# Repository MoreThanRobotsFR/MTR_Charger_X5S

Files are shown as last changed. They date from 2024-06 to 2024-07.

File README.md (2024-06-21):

<!-- markdownlint-configure-file { "MD004": { "style": "consistent" } } -->
<!-- markdownlint-disable MD033 -->
<p align="center">
    <a href="https://morethanrobotsfr.github.io/MoreThanRobots/">
        MTR
    </a>
    <br>
    <strong>Coding, Hardware and fun !</strong>
</p>
<!-- markdownlint-enable MD033 -->

<body style="background-color:#FFBF00;">
</body>

# MoreThanRobots
* Check the [YOUTUBE-EN-FR](https://www.youtube.com/@morethanrobots) channel.

# Coding
* C/C++
* Python
* MicroPython
* CircuitPython 

# Hardward
* Arduino Uno / Mega / Nano
* Raspberry Pi / Pico / RP2040
* NodeMCU ESP8266 / ESP32

# Schematic
* Kicad
* Altium designer

# Last Project
* [MTR Reflow Plate](https://github.com/MoreThanRobotsFR/MTR_Reflow_Plate)
* [MTR Tiny MD](https://github.com/MoreThanRobotsFR/MTR_Tiny_MD)
* [MTR Multisensor](https://github.com/MoreThanRobotsFR/MTR_C3_TempHum)

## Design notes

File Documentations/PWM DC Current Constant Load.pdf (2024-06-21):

# RC Filter Design for PWM Signal

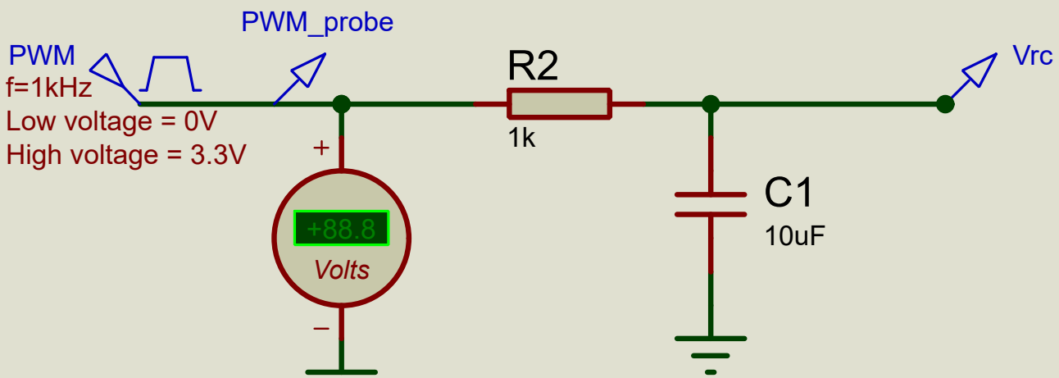
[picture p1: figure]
PWM; +88.8 Volts; f=1kHz Low voltage = 0V High voltage = 3.3V; PWM_probe; Vrc

Determine if your RC values are suitable, let's analyze the RC low-pass filter with the following values:

PWM frequency

## Cutoff Frequency Calculation

The cutoff frequency of the RC low-pass filter is given by:

Substituting the given values:

### R2 = 1kΩ C1 = 10μF fPWM = 1kHz

fc

fc =

### 2πR2C1

1

fc =
2π × 1000 × 10 × 10⁻⁶

1

### fc ≈ 15.9Hz

## Comparison with PWM Frequency

The PWM frequency is . For effective smoothing of the PWM signal into a DC voltage, the cutoff frequency of the RC filter should be much lower than the PWM frequency.

In this case:

A ratio of | indicates that the RC filter will effectively smooth the PWM signal, as the cutoff
frequency is much lower than the PWM frequency.

## Time Constant

The time constant of the RC filter is:

Substituting the given values:

The time constant indicates how quickly the filter responds to changes in the PWM signal. A 10 ms time constant is reasonable for a 1 kHz PWM signal, allowing the filter to respond smoothly to the changes in the PWM duty cycle.

### 1kHz

=
fc

fPWM
≈
15.9Hz

1000Hz
62.9

≈ 62.9

τ

### τ = R2 × C1

τ = 1000 × 10 × 10

−6

### τ = 0.01s = 10ms

## Simulation

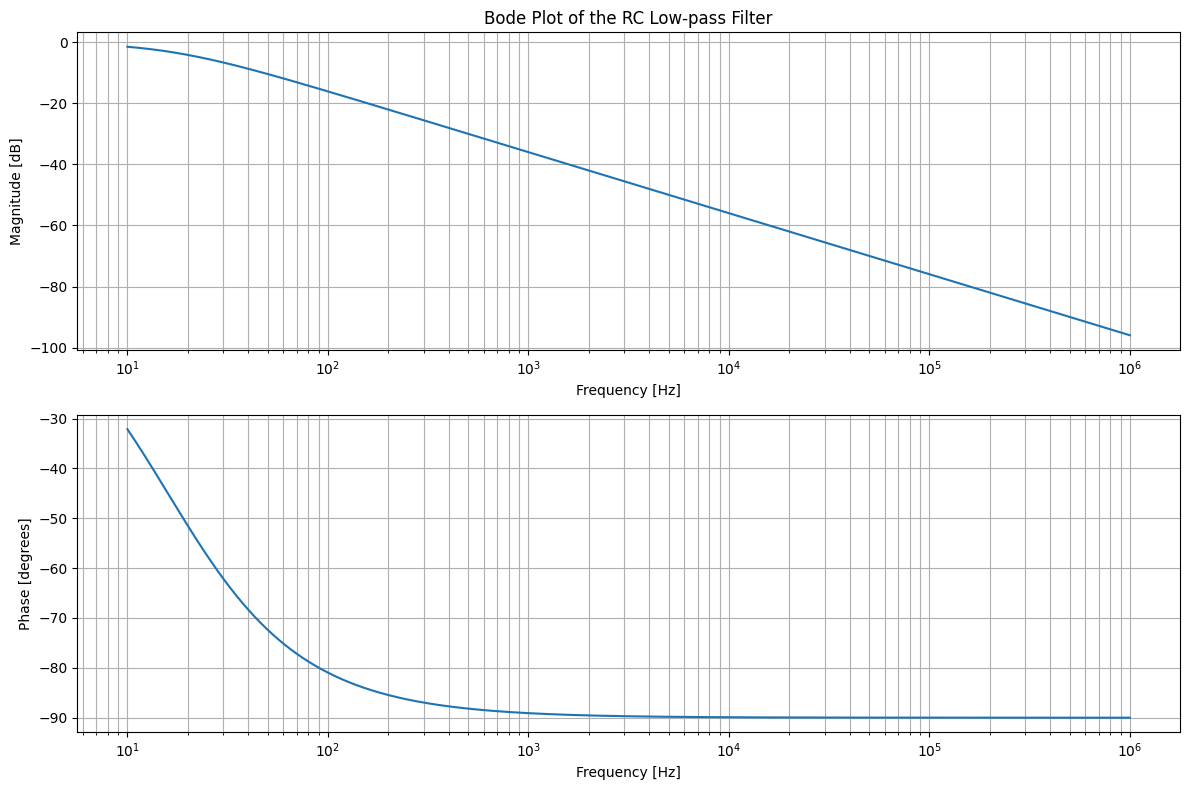
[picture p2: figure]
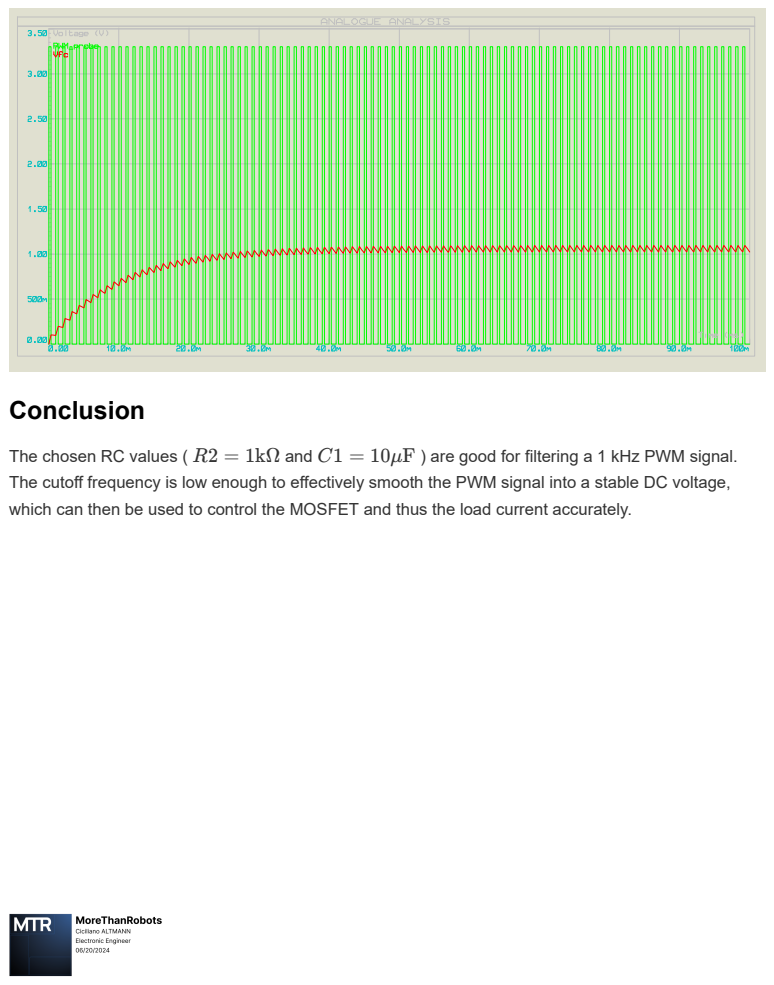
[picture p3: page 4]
Conclusion; The chosen RC values (; and; ) are good for filtering a 1 kHz PWM signal.

The cutoff frequency is low enough to effectively smooth the PWM signal into a stable DC voltage,
which can then be used to control the MOSFET and thus the load current accurately.

# PWM Signal to Load Current Conversion

The circuit in the schematic is a typical application of a Pulse Width Modulation (PWM) signal used to control the current through a load. Here’s a step-by-step explanation of how the PWM signal affects the current drawn from the load:

1. PWM Signal:
The PWM signal has a frequency | and a duty cycle (pulse width) of 50%.
The low voltage of the PWM signal is 0V, and the high voltage is 3.3V.
2. RC Low-pass Filter:
The resistor | and the capacitor | form a low-pass filter.
The purpose of this filter is to convert the PWM signal into a DC voltage.
3. Voltage Conversion:
The DC voltage after the filter | can be calculated using the duty cycle | of the PWM
signal:
Where | .
For a 50% duty cycle:
4. Operational Amplifier:
The operational amplifier | (AD8032) is configured as a voltage follower or buffer.
The voltage at the non-inverting input (pin 3) is the filtered DC voltage | .
5. MOSFET Control:
The MOSFET | (2N7269) is controlled by the output of the operational amplifier.
The current through the load | (1Ω) is determined by the voltage at the gate of the
MOSFET.
6. Load Current Calculation:
The voltage across is the same as the voltage at the source of the MOSFET, which is .
The current through the load can be calculated using Ohm’s Law:

### f = 1kHz

R2 = 1kΩ | C1 = 10μF
VDC | D

VDC = D × Vhigh

### Vhigh = 3.3V

### VDC = 0.5 × 3.3V = 1.65V

U2 : A

VDC

Q1
R1

R1

VDC
Iload

Given | and | :

## Relation Between PWM Duty Cycle and Load Current

The load current | is directly proportional to the duty cycle | of the PWM signal:

## Effect of Frequency

The frequency of the PWM signal affects the efficiency of the low-pass filter. The cutoff frequency of the filter should be much lower than the PWM frequency to ensure proper smoothing. For
and | :

Since 15.9 Hz is much lower than 1 kHz, the filter effectively smooths the PWM signal, and the frequency does not directly affect the load current but ensures the DC voltage is properly formed.

## Summary

The load current is proportional to the PWM duty cycle.
For a duty cycle | and high voltage | , the load current | is:

The frequency ensures the PWM signal is properly filtered to a DC voltage by the RC filter.

Iload =
R1

VDC

R1 = 1Ω | VDC = 1.65V
Iload = | =
1Ω

1.65V
1.65A
Iload | D

Iload = D ×
R1

Vhigh

fc

### R2 = 1kΩ C1 = 10μF

fc = | ≈

### 2πR2C1

1
15.9Hz
D | Vhigh = 3.3V | Iload
| Iload = D ×
1Ω

3.3V

# PWM Control of Load Current

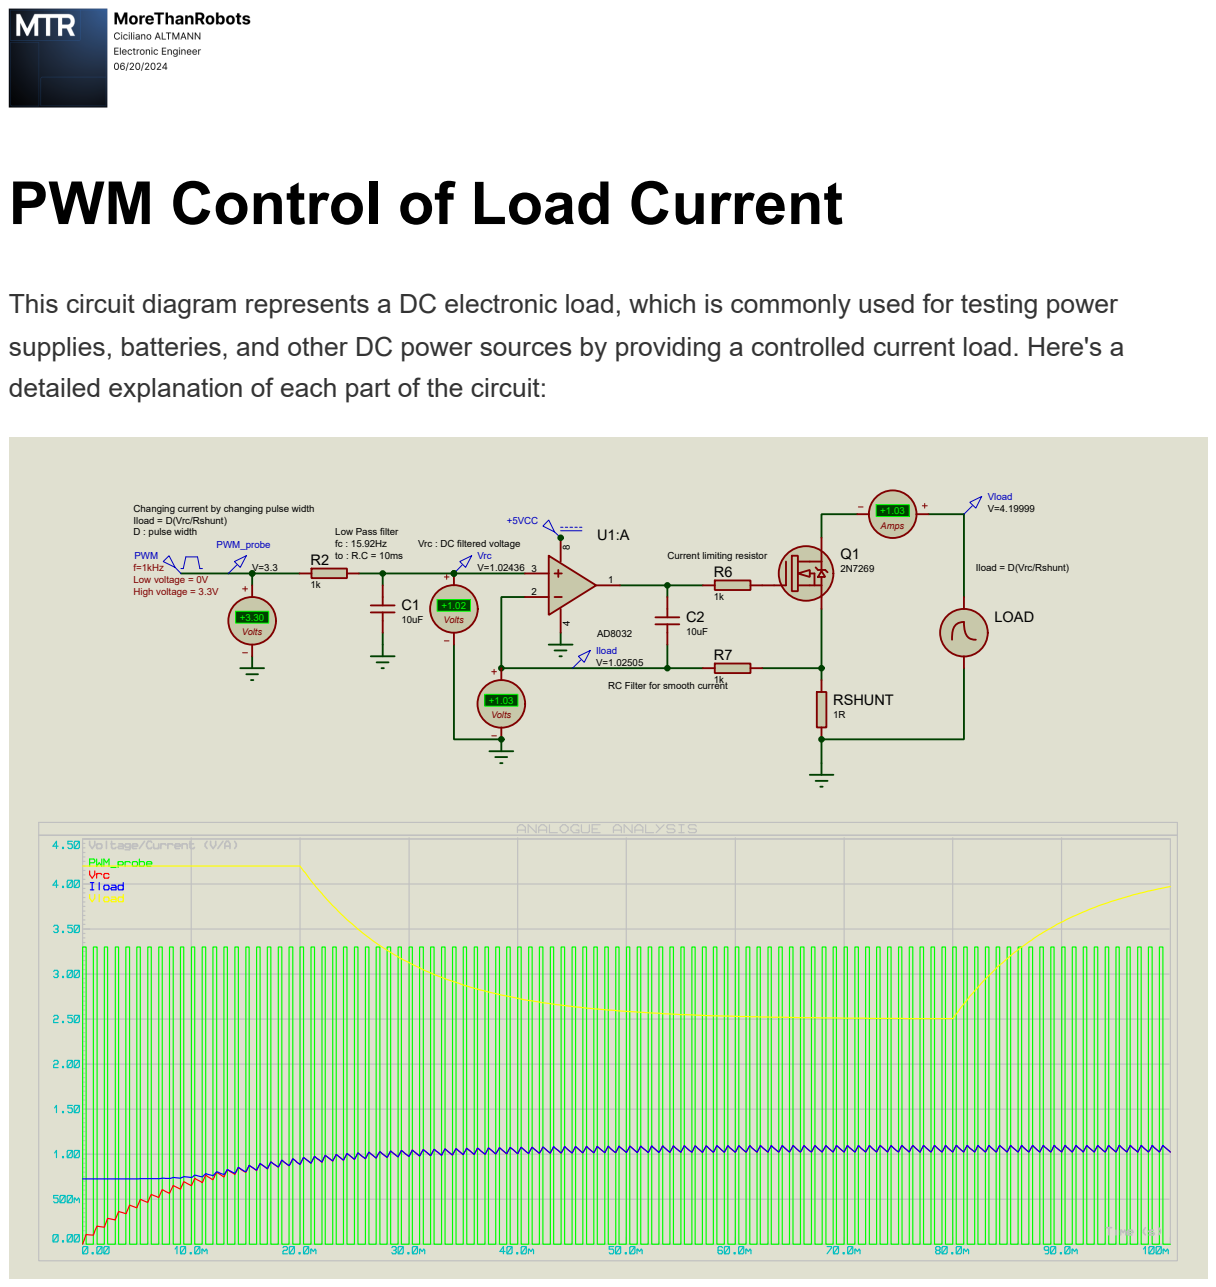
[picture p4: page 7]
RSHUNT; PWM; Amps; Volts; LOAD; +5VCC; f=1kHz Low voltage = 0V High voltage = 3.3V; PWM_probe; Vrc V=1.02436; Vload V=4.19999; Iload V=1.02505; Low Pass filter

This circuit diagram represents a DC electronic load, which is commonly used for testing power
supplies, batteries, and other DC power sources by providing a controlled current load. Here's a
detailed explanation of each part of the circuit:

Changing current by changing pulse width
Iload = D(Vrc/Rshunt)
D : pulse width

Vrc : DC filtered voltage

Current limiting resistor

RC Filter for smooth current

## Components:

1. PWM Source and RC Filter:
PWM Source: The PWM signal (PWM probe) has a high voltage of 3.3V, low voltage of 0V, and a frequency of 1kHz.
R2 (1kΩ) and C1 (10µF): This forms a low-pass filter with a cutoff frequency of approximately 15.92Hz. The filtered PWM signal is converted to a DC voltage (Vrc) at node 1, which is a smoothed version of the PWM signal.
2. Operational Amplifier (Op-Amp) U1:A:
U1:A (AD8032): This op-amp is configured as a voltage follower (buffer) to isolate the low-pass filter from the rest of the circuit and provide a stable DC voltage to the gate of the MOSFET (Q1).
R6 (1kΩ) and C2 (10µF): These components form an additional filter to smooth out any remaining ripple from the filtered PWM signal.
3. MOSFET (Q1 - 2N7269):
Q1: This is an N-channel MOSFET acting as the variable resistor controlled by the voltage from the op-amp. The MOSFET regulates the current flowing through the load (represented by a voltage source in series with RSHUNT).
4. Current Sensing and Feedback:
RSHUNT (1Ω): This shunt resistor is used to measure the current flowing through the load. The voltage across RSHUNT (Vload) is directly proportional to the current (Iload).
R7 (1kΩ): This resistor, along with C2, forms a filter to smooth the current measurement signal.

## Working Principle:

1. PWM Control: The PWM signal is filtered by the RC network (R2 and C1) to produce a DC voltage (Vrc). The duty cycle of the PWM signal determines the average DC voltage output by the filter.
2. Voltage Buffering: The filtered voltage (Vrc) is fed into the non-inverting input of the op-amp (U1:A), which buffers the signal and drives the gate of the MOSFET (Q1).
3. Current Regulation: The op-amp adjusts the gate voltage of Q1 to regulate the current flowing
through the load. The current through the load is given by | , where D is the duty
cycle of the PWM signal.

Iload = D Rshunt

Vrc

4. Feedback Loop: The voltage across the shunt resistor (RSHUNT) is fed back to the inverting input of the op-amp (U1:A). This feedback mechanism helps maintain a constant current through the load, as determined by the voltage Vrc.

## Simulation Results:

Green Trace (PWM_probe): This shows the PWM signal with high frequency and varying duty cycle.
Red Trace (Vrc): This represents the filtered DC voltage after the low-pass filter.
Yellow Trace (Vload): This represents the voltage across the load, varies between 4.2 and 2.5V. Blue Trace (Iload): This shows the current through the load, which stabilizes around 1.03A, showing the effective regulation of the load current despite the variation of the load voltage.

In summary, this circuit uses a PWM signal to control a MOSFET via an op-amp buffer, allowing precise control of the load current. The current is sensed through a shunt resistor, and feedback ensures stable current regulation. This setup is ideal for creating a programmable electronic load for testing power supplies and batteries.

# Author

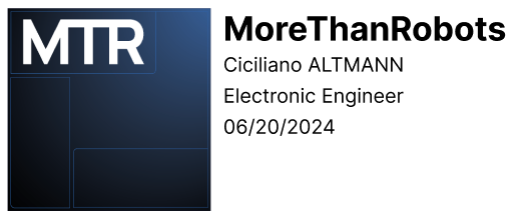
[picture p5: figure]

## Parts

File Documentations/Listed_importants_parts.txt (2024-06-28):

Mfr. Part # LMC6482AIMX/NOPB  LCSC Part # C12620    : Precision OpAmps
Mfr. Part # LMV358IDR         LCSC Part # C63813    : Rail-to-Rail OpAmps
Mfr. Part # IRLZ44NPBF        LCSC Part # C38774    : Power N-Channel MOSFET
Mfr. Part # TPL0401B-10DCKR   LCSC Part # C2666599  : Digital potentiometer
Mfr. Part # ADS7830IPWR       LCSC Part # C161747   : 8-Channel Sampling ADC
Mfr. Part # TCA9535PWR        LCSC Part # C130204   : 16-bit IO Expenders
Mfr. Part # STUSB4500QTR      LCSC Part # C2678061  : USB-C PD sink controller
Mfr. Part # MCP73833-AMI/MF   LCSC Part # C635264   : Battery Management Circuit
Mfr. Part # RP2040            LCSC Part # C2040     : µContoler
Mfr. Part # W25Q16JVUXIQ      LCSC Part # C2843335  : 16MB QSPI Flash
Mfr. Part # X322512MSB4SI     LCSC Part # C9002     : 12MHz Crystal Oscillators
Mfr. Part # BH-18650-B5BA016  LCSC Part # C19184086 : 18650 Battery Case
Mfr. Part # TF-04A            LCSC Part # C145799   : microSD card slot
Mfr. Part # TPS63051YFFR      LCSC Part # C2879621  : VBuck 3.3V 1A
Mfr. Part # TPS62163DSGR      LCSC Part # C97534    : VBuck 5V 1A
Mfr. Part # WS2812B-2020      LCSC Part # C965555   : LED RGB
Mfr. Part # HS96F04BF         LCSC Part # C5139757  : OLED Display 0.96in 128x64
Mfr. Part # PCSR2512DR033M6   LCSC Part # C20417217 : Rshunt 33 mOhms 0.5% package 2512
Mfr. Part # FRH0603D1001TSV   LCSC Part # C3013341  : 1 kOhms 0.5% package 0603
Mfr. Part # ARG03DTC1003      LCSC Part # C2758260  : 100 kOhms 0.5% package 0603
Mfr. Part # NCP18XH103F03RB   LCSC Part # C13564    : NTC 10kOhms Package 0603
Mfr. Part # SF4007SM5         LCSC Part # C2149489  : Cooling fan 5V
Mfr. Part # AO3480C           LCSC Part # C705501   : Logic N-Channel MOSFET
Mfr. Part # AO3401A           LCSC Part # C15127    : Logic P-Channel MOSFET
Mfr. Part # DS1337S+T&R       LCSC Part # C9867     : Real Time Clock
Mfr. Part # T803832768KRDDZTX LCSC Part # C5917315  : 32.768kHz Crystal Oscillators
Mfr. Part # BS-12-B3AA003     LCSC Part # C964723   : CR1220 Battery Case
Mfr. Part # 24.243.2          LCSC Part # C7437322  : Black Banana Connectors
Mfr. Part # 24.243.1          LCSC Part # C7437321  : Red Banana Connectors
Mfr. Part # CD74HCT4051M96    LCSC Part # C406862   : Multiplexer 1 to 8

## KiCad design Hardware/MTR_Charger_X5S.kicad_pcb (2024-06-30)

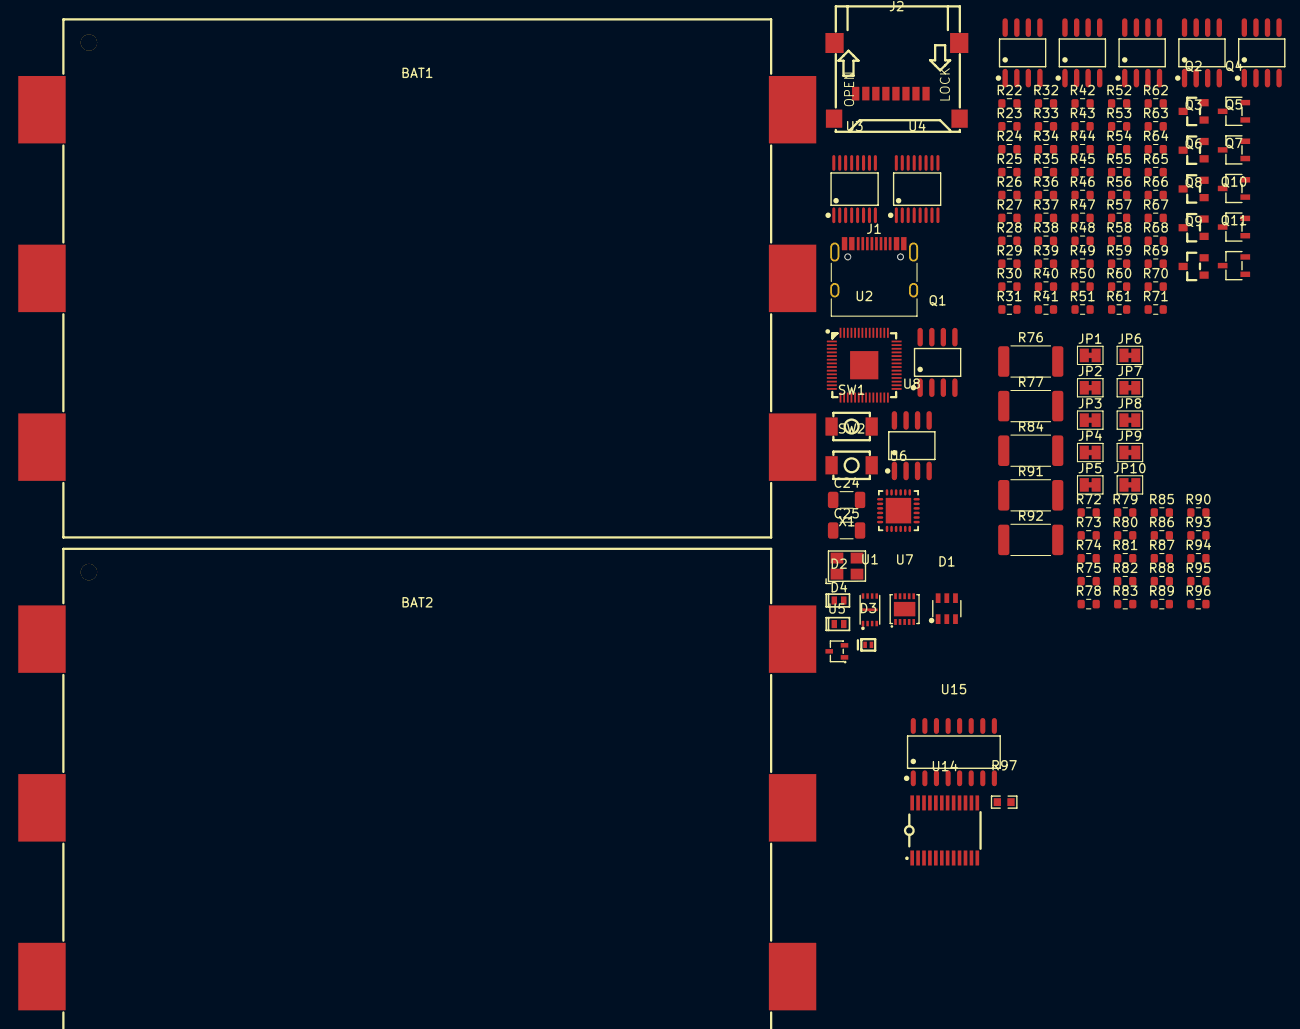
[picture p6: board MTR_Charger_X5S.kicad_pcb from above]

Board: 2 copper layers, 125 parts (0 on the bottom side), 118 nets, no tracks yet.

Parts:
BAT1, BAT2: BH-18650-B5BA016; BAT-SMD_BH-18650-B5BA016
C24, C25: 1uF; C_1206_3216Metric
D1: USBLC6-2SC6; SOT-23-6_L2.9-W1.6-P0.95-LS2.8-BL
D2, D4: ESDA25P35; DFN1610-2_L1.6-W1.0-P1.05-RD
D3: D_Schottky_Small; X2-DFN1006-2_L1.0-W0.6-P0.65-RD
J1: Korean Hroparts Elec TYPE-C-31-M-12; USB_C_Receptacle_HRO_TYPE-C-31-M-12
J2: Micro_SD_Card; TF-SMD_TF-04A
JP1, JP2, JP3, JP4, JP5, JP6, JP7, JP8, JP9, JP10: SolderJumper_2_Bridged; SolderJumper-2_P1.3mm_Bridged_Pad1.0x1.5mm
Q1: IRF7324TRPBF; SOIC-8_L4.9-W3.9-P1.27-LS6.0-BL
Q2, Q3, Q6, Q8, Q9: AO3401A; SOT-23_L2.9-W1.3-P1.90-LS2.4-BR
Q4, Q5, Q7, Q10, Q11: AO3480C; SOT-23-3_L2.9-W1.6-P1.90-LS2.8-BR
R22, R23, R24, R25, R26, R27, R28, R29, R30, R31, R32, R33, R34, R35, R36, R37, R38, R39, R40, R41, R42, R43, R44, R45, R46, R47, R48, R49, R50, R51, R52, R53, R54, R55, R56, R57, R58, R59, R60, R61, R62, R63, R64, R65, R66, R67, R68, R69, R70, R71, R72, R73, R80, R81, R82, R86, R87, R88, R95, R96: 100k; R_0603_1608Metric
R74, R75, R78, R79, R83, R85, R89, R90, R93, R94: 1k; R_0603_1608Metric
R76, R77, R84, R91, R92: 33m; R_2512_6332Metric
R97: NCP18XH103F03RB; R0603
SW1: Boot; SW-SMD_L4.0-W3.0-LS5.0
SW2: Reset; SW-SMD_L4.0-W3.0-LS5.0
U1: W25Q16JVUXIQ; USON-8_L3.0-W2.0-P0.50-BL-EP
U2: RP2040; LQFN-56_L7.0-W7.0-P0.4-EP
U3, U4: ADS7830IPWR; TSSOP-16_L5.0-W4.4-P0.65-LS6.4-BL
U5: ESDA25W; SOT-323-3_L2.1-W1.3-P1.32-LS2.1-BR
U6: STUSB4500QTR; QFN-24_L4.0-W4.0-P0.50-BL-EP2.8
U7: MCP73833-AMI/MF; DFN-10_L3.0-W3.0-P0.50-BL-EP-1
U8: LMV358IDR; SOIC-8_L4.9-W3.9-P1.27-LS6.0-BL
U9, U10, U11, U12, U13: LMC6482AIMX/NOPB; SOIC-8_L4.9-W3.9-P1.27-LS6.0-BL
U14: TCA9535PWR_C130204; TSSOP-24_L7.8-W4.4-P0.65-LS6.4-BL
U15: CD74HCT4051M96; SOP-16_L10.0-W3.9-P1.27-LS6.0-BL
X1: X322512MSB4SI; OSC-SMD_4P-L3.2-W2.5-BL

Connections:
+1V1: U2.23 (DVDD), U2.45 (VREG_VOUT), U2.50 (DVDD)
+3.3V: U1.8 (VCC), U2.1 (IOVDD), U2.10 (IOVDD), U2.22 (IOVDD), U2.33 (IOVDD), U2.42 (IOVDD), U2.43 (ADC_AVDD), U2.44 (VREG_IN), U2.48 (USB_VDD), U2.49 (IOVDD), U3.16 (+VDD), U4.16 (+VDD), U15.16 (VCC)
+5V: U9.8 (VCC+), U10.8 (VCC+), U11.8 (VCC+), U12.8 (VCC+), U13.8 (VCC+)
/Batteries current sensing/sence_01+: JP1.1 (A), R74.1, R76.1
/Batteries current sensing/sence_01-: JP3.1 (A), R76.2, R78.1
/Batteries current sensing/sence_02+: JP2.1 (A), R75.1, R77.1
/Batteries current sensing/sence_02-: JP4.1 (A), R77.2, R79.1
/Batteries current sensing/sence_03+: JP5.1 (A), R83.1, R84.1
/Batteries current sensing/sence_03-: JP6.1 (A), R84.2, R85.1
/Batteries current sensing/sence_04+: JP7.1 (A), R89.1, R91.1
/Batteries current sensing/sence_04-: JP9.1 (A), R91.2, R93.1
/Batteries current sensing/sence_05+: JP8.1 (A), R90.1, R92.1
/Batteries current sensing/sence_05-: JP10.1 (A), R92.2, R94.1
/CC1: J1.A5 (CC1), U5.1 (K), U6.1 (CC1DB), U6.2 (CC1)
/CC2: J1.B5 (CC2), U5.2 (K), U6.4 (CC2), U6.5 (CC2DB)
/D+: D1.3 (L2), J1.A6 (D+), J1.B6 (D+)
/D-: D1.1 (L1), J1.A7 (D-), J1.B7 (D-)
/Mux_CELL_01_S0: U14.9 (P05), U15.11 (S0)
/Mux_CELL_01_S1: U14.8 (P04), U15.10 (S1)
/Mux_CELL_01_S2: U14.7 (P03), U15.9 (S2)
/PG_Cell_01: U7.7 (~PG), U14.4 (P00)
/PROG_CELL_01: U7.6 (PROG), U15.3 (A)
/STAT1_Cell_01: U7.3 (STAT1), U14.6 (P02)
/STAT2_Cell_01: U7.4 (STAT2), U14.5 (P01)
/XIN: U2.20 (XIN), X1.3
/XOUT: U2.21 (XOUT), X1.1
ALERT: U2.8 (GPIO6), U6.19 (ALERT)
CELL_01+: BAT1.2, JP3.2 (B), Q2.2 (S), R27.2
CELL_02+: BAT1.4, JP4.2 (B), Q3.2 (S), R29.2
CELL_03+: BAT1.6, JP6.2 (B), Q6.2 (S), R45.2
CELL_04+: BAT2.2, JP9.2 (B), Q9.2 (S), R60.2
CELL_05+: BAT2.4, JP10.2 (B), Q8.2 (S), R57.2
CHARGING_01: C25.1, JP1.2 (B), U7.9 (VBAT), U7.10 (VBAT)
Current_cell_01: R80.2, U4.1 (CH0), U9.1
Current_cell_02: R81.2, U4.2 (CH1), U10.1
Current_cell_03: R86.2, U4.3 (CH2), U11.1
Current_cell_04: R95.2, U4.4 (CH3), U12.1
Current_cell_05: R96.2, U4.5 (CH4), U13.1
GND: C24.2, C25.2, D1.2 (VN), D2.2 (A2), D4.2 (A2), J1.A1 (GND), J1.A12 (GND), J1.B1 (GND), J1.B12 (GND), J1.S1 (SHIELD), R22.1, R23.1, R42.1, R52.1, R54.1, R72.2, R73.2, R82.2, R87.2, R88.2, R97.1, SW1.1, SW2.1, U1.4 (GND), U2.19 (TESTEN), U2.57 (GND), U5.3 (A), U6.3 (NC), U6.10 (GND), U6.22 (VSYS), U6.25 (EP), U7.5 (VSS), U7.11 (PAD), U9.4 (GND), U10.4 (GND), U11.4 (GND), U12.4 (GND), U13.4 (GND), U14.12 (GND), U15.6 (~E), U15.7 (VEE), U15.8 (GND), X1.2, X1.4
unnamed: D1.5 (VP), D2.1 (A1), D3.2 (A), J1.A4 (VBUS), J1.A9 (VBUS), J1.B4 (VBUS), J1.B9 (VBUS), Q1.7 (D1), Q1.8 (D1)
unnamed: Q1.2 (G1), Q1.4 (G2)
unnamed: Q1.1 (S1), Q1.3 (S2), U6.24 (VDD)
unnamed: Q2.3 (D), R38.2
unnamed: Q2.1 (G), Q4.3 (D), R27.1
unnamed: Q3.3 (D), R39.2
unnamed: Q3.1 (G), Q5.3 (D), R29.1
unnamed: Q4.2 (S), R40.1
unnamed: Q5.2 (S), R41.1
unnamed: Q6.3 (D), R50.2
unnamed: Q6.1 (G), Q7.3 (D), R45.1
unnamed: Q7.2 (S), R51.1
unnamed: Q8.3 (D), R67.2
unnamed: Q9.3 (D), R69.2
unnamed: Q8.1 (G), Q10.3 (D), R57.1
unnamed: Q10.2 (S), R70.1
unnamed: Q9.1 (G), Q11.3 (D), R60.1
unnamed: Q11.2 (S), R71.1
unnamed: R22.2, R24.1
unnamed: R23.2, R25.1
unnamed: R24.2, R26.2
unnamed: R25.2, R28.2
unnamed: R26.1, R30.1
unnamed: R28.1, R31.1
unnamed: R30.2, R32.1
unnamed: R31.2, R33.1
unnamed: R32.2, R34.2
unnamed: R33.2, R35.2
unnamed: R34.1, R36.1
unnamed: R35.1, R37.1
unnamed: R36.2, R38.1, R40.2, U9.5
unnamed: R37.2, R39.1, R41.2, U10.5
unnamed: R42.2, R43.1
unnamed: R43.2, R44.2
unnamed: R44.1, R46.1
unnamed: R46.2, R47.1
unnamed: R47.2, R48.2
unnamed: R48.1, R49.1
unnamed: R49.2, R50.1, R51.2, U11.5
unnamed: R52.2, R53.1
unnamed: R53.2, R56.2
unnamed: R54.2, R55.1
unnamed: R55.2, R59.2
unnamed: R56.1, R58.1
unnamed: R58.2, R61.1
unnamed: R59.1, R62.1
unnamed: R61.2, R64.2
unnamed: R62.2, R63.1
unnamed: R63.2, R66.2
unnamed: R64.1, R65.1
unnamed: R65.2, R67.1, R70.2, U12.5
unnamed: R66.1, R68.1
unnamed: R68.2, R69.1, R71.2, U13.5
unnamed: R72.1, R74.2, U9.3
unnamed: R73.1, R75.2, U10.3
unnamed: R78.2, R80.1, U9.2
unnamed: R79.2, R81.1, U10.2
unnamed: R82.1, R83.2, U11.3
unnamed: R85.2, R86.1, U11.2
unnamed: R87.1, R89.2, U12.3
unnamed: R88.1, R90.2, U13.3
unnamed: R93.2, R95.1, U12.2
unnamed: R94.2, R96.1, U13.2
unnamed: R97.2, U7.8 (THERM)
unnamed: U8.1, U8.6
QSPI_CLK: U1.6 (CLK), U2.52 (QSPI_SCLK)
QSPI_SD0: U1.5 (DI(IO0)), U2.53 (QSPI_SD0)
QSPI_SD1: U1.2 (DO(IO1)), U2.55 (QSPI_SD1)
QSPI_SD2: U1.3 (WP#(IO2)), U2.54 (QSPI_SD2)
QSPI_SD3: U1.7 (RESET#(IO3)), U2.51 (QSPI_SD3)
QSPI_SS: U1.1 (~CS), U2.56 (QSPI_SS)
SCL: U2.7 (GPIO5), U3.14 (SCL), U4.14 (SCL), U6.7 (SCL)
SDA: U2.6 (GPIO4), U3.15 (SDA), U4.15 (SDA), U6.8 (SDA)
Voltage_cell_01: U3.1 (CH0), U9.6, U9.7
Voltage_cell_02: U3.2 (CH1), U10.6, U10.7
Voltage_cell_03: U3.3 (CH2), U11.6, U11.7
Voltage_cell_04: U3.4 (CH3), U13.6, U13.7
Voltage_cell_05: U3.5 (CH4), U12.6, U12.7
Vsnk: C24.1, D4.1 (A1), Q1.5 (D2), Q1.6 (D2), U7.1 (VDD), U7.2 (VDD)

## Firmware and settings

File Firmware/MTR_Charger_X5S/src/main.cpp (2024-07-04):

#include <Wire.h>
#include <MTR_STUSB4500.h>
#include <MTR_ADS7830.h>

#define ADS7830_ADDRESS 0x48 // I2C Address (assuming A0 and A1 are both tied to GND)

// Create an instance of the ADS7830 class
MTR_ADS7830 adc;

// Create an instance of the STUSB4500 class
MTR_STUSB4500 stusb4500;

void setup() {

  // Initialize the serial port
  Serial.begin(9600);

  adc.init();
  
  // Initialize the STUSB4500 device
  stusb4500.init();

  // Set the number of sink PDOs to 1
  stusb4500.setPdoNumber(1);

  // Set the voltage value for SNK_PDO1 to 5V
  // can't be set, because is hardcoded to 5V

  // Set the current value for SNK_PDO1 to 1A
  stusb4500.setISinkPdo1(1000);

}

void loop() {
  // Get the alert status from the STUSB4500
  uint8_t alertStatus;
  if (stusb4500.getAlertStatus(alertStatus)) {
    Serial.print("Alert status: 0x");
    Serial.println(alertStatus, HEX);
  }

  // Get the port status from the STUSB4500
  uint8_t portStatus;
  if (stusb4500.getPortStatus(portStatus)) {
    Serial.print("Port status: 0x");
    Serial.println(portStatus, HEX);
  }

  // Get the device ID from the STUSB4500
  uint8_t deviceID;
  if (stusb4500.getDeviceID(deviceID)) {
    Serial.print("Device ID: 0x");
    Serial.println(deviceID, HEX);
  }

  for (uint8_t i = 0; i < 8; i++) {
    uint8_t value = adc.readChannel(i);
    Serial.print("Channel ");
    Serial.print(i);
    Serial.print(": ");
    Serial.println(value);
  }
    
  delay(1000); // Wait for a second before the next read
}

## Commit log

2024-06-24 USC C and PD done
    [MTR_Charger_X5S.kicad_sch]
2024-06-24 RP2040 and QSPI Flash done
    [Auto_Power_Switch_Circuit.kicad_sch, MTR_Charger_X5S.kicad_sch, Periodic_battery_level_measurement_simulation.kicad_sch]
2024-06-24 Current and Voltage sensing done
    [Batteries_current_sensing.kicad_sch, Batteries_voltage_sensing.kicad_sch, MTR_Charger_X5S.kicad_pcb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]
2024-06-28 Add Mux for Battery charging current selection
    [MTR_Charger_X5S.kicad_pcb, MTR_Charger_X5S.kicad_sch]
2024-07-02 Add platformIO
    [MTR_Charger_X5S.kicad_sch]
2024-07-06 Add battery ic
    [Batteries_Charging_IC.kicad_sch, MTR_Charger_X5S.kicad_sch]
